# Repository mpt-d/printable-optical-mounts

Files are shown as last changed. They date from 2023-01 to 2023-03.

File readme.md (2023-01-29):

-------------------------------
3D-Printable Optical Components
-------------------------------

## Mission Statement

The objective of this project is to produce a free library of optical components that can be manufactured by users through 3D printing or milling. 

The current scope of the project encompasses a cage system, a post system and various mounts. It does not include hard-to-manufacutre components such as lenses, mirrors and filters

## Disclaimer

This project is not ready for use. Do not attempt to manufacture any of the components.

## Manufacturing Requirements

### Equipment

- FDM or SLA 3D printers
- A hand saw and vice (for cutting cage poles to size)

### Software

- FreeCAD (only if viewing or modifying components)
- A 3D slicer compatible with your 3D printer

### Materials

FDM filament or SLA resin depending on the chosen manufacturing technique.

### Other Parts

- M4 and M6 thread inserts (see BOM)
- M4 thumbscrews 
- M5 grub screws
- M1.6 nylon-tipped grub screws
- Ø6mm aluminium rods (for use in cage system)

## Implemented Modules

### Main Groups:

- 30mm cage system
- Post and pedestal system
- Various compatible optical mounts

### 30mm Cage System

General: 

- [done] Base mat 
- [done] Post holders 
- [done] Posts 
- [done] Pedestals 
- [done] Clamping fork 

Mounts:  

- [done] V-groove lens/laser mount 
- [done] Filter/mirror mount 
- [done] Prism platform 
- [done] Cylindrical object mount 
- [done] XY translation lens holder 
- [done] XY rotation lens holder 
- [done] Iris 

Cage: 

- [part] 90° Junction 
- [done] Side branch mount 
- [part] Mirror clamp 
- [done] Spiral lens holder 
- [done] XY rotation lens holder 
- [done] XY translation lens
- [done] Poles 
- [done] Post mount 
- [done] Structural tie

# Assembly

## Screws

All threads larger than M3 require corresponding thread inserts. These can be pressed to FMD printed components by heating them with a soldering iron. For the M1.6 grub screws used to clamp removable parts in place, threads must be tapped manually. It is recommended to use nylon-tipped set screws to avoid damaging clamped equipment.

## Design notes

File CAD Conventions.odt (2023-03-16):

CAD Conventions

Overview

To maintain homogeneity across all module designs, we should attempt to maintain a common structure across all FreeCAD files. This document hopes to formalise names and hierarchies.

Module Scope

Minimum Viable Module Set | General: - [done] [bom] [drw] Base mat - [done] [bom] [drw] Post holders - [done] [bom] [drw] Posts - [done] [bom] Pedestals - [done] [bom] Clamping fork Mounts: - [done] [bom] [drw] V-groove lens/laser mount - [done] [bom] Filter/mirror mount - [done] [bom] Prism platform Cage: - [done] [bom] Poles - [done] [bom] Post mount - [done] [bom] Structural tie
Preferred Module Set | General: - [done] [bom] [drw] Cylindrical object mount - [done] [bom] XY translation lens holder - [done] [bom] [drw] XY rotation lens holder Cage: - [done] [bom] 90° Junction - [done] [bom] Cross junction - [done] [bom] Side branch mount - [done] [bom] Spiral lens holder - [done] [bom] XY rotation lens holder - [done] [bom] XY translation lens holder - [done] [bom] Pole-to-pole tie
Extended Module Set | General: - Motorised rotating filter mount - [done] [bom] Iris - Optical rail Cage: - Shearing interferometer casing - Adapters for competing cage systems

Document Hierarchy

All geometry (such as Bodies created with Part Design workbench) should be encapsulated within a Part object. Multiple parts can be defined within the same document, but if they are meant to be separate objects, they should be enclosed different Parts.

Parts can be created with a button present in both the Part Design and Part workbenches.

File Naming Conventions

File names should be lower case and must not contain spaces. Descriptors filenames must be separated with dashes.

General format:

<name>_<name>-<descriptor>

Examples:

junction-cross

Junction-corner

post_holder-60mm

post_holder-70mm

Part Naming Conventions

Parts should be given a friendly display name that can contain spaces and capitals.

All geometry within the Part (Bodies, primitives, etc.) should be named in snake_case. The naming of Part Design features and sketches does not matter provided they are descriptive.

Parameter Aliasing

Where possible, dimensions should be referenced from a spreadsheet rather than hard-coded into the sketch or feature. This allows the creation of multiple linked copies of parts whose parameters can be altered independently.

Caution: When creating parametric models, values should be inherited from a single spreadsheet in a central file to avoid dependency loops. For example, if models FILE1 and FILE2 require a common value, they should both inherit it from a spreadsheet in FILE3. FILE1 and FILE2 must not reference each other directly.

Alias Naming Conventions

FreeCAD Parameter aliases start with a sequence that indicates its type followed by its name. All characters should be lower case, and words should be separated by underscores (snake_case).

<parameter key>_<name>

For example, the inner radius of a shaft could be called ri_shaft.

Key | Value
w | Width
h | Height
t | Thickness
wt | Wall Thickness
l | Length
[dr]i | Inner radius/diameter
[dr]o | Outer radius/diameter
[dr]m | Major radius/diameter
[dr]mi | Minor radius/diameter
a | Angle
pt | Pitch
off | Offset
c | Clearance

Configuration Tables

Configuration tables allow parts to be switched between multiple sets of parameters defined in a spreadsheet. This is useful for creating parts which follow the same pattern but have altered dimensions.

Tutorials:

https://www.youtube.com/watch?v=D0f7bkNGAOg&t=346s

https://www.youtube.com/watch?v=nAmwGUuvnjs

## General Design Features

FreeCAD Topological Naming Problem

A major issue in FreeCAD is that the creation of new geometry can cause geometry that depends on it to break. This can result in fillets on the wrong edges, sketches attached to curves and all sorts of weird things.

More information, including how to avoid the issue: https://wiki.freecadweb.org/Topological_naming_problem

Alternatively, the Linkstage3 branch of FreeCAD (maintained by Realthunder) can be used. This includes automatic and backwards-compatible solutions for the topological naming problem that work in most cases:

https://github.com/realthunder/FreeCAD/releases

Fillets

It is recommended to replace sharp edges with fillets to avoid stress concentrations.

For visual consistency across all parts, try to make fillets with lengths of 1mm or 0.5mm.

Design for 3D Printing

To be printed effectively a part must have:

- Good adhesion with the platform.
- No significant overhangs

Parts should have a flat surface that will be in contact with the base during manufacture. Overhangs should be avoided.

Threads

For maximum accessibility, built-in threads below M5 are to be avoided in favour of metal thread inserts. This removes the requirement for a very high-quality 3D printer which some users will have access to. If a built-in thread is required, it can be generated with the Hole feature in the Part Design workbench.

A question about 3D-printing threads:

https://3dprinting.stackexchange.com/questions/3160/printing-screws-is-the-output-usable-m3-or-m4

Drawings

Drawings must be made on the TechDraw workbench. To start a new drawing, click on ‘Insert Page Using Template’ and select ‘A?_Landscape_ISO7200_Pep.svg’. The title block can be filled out by double-clicking on the green highlighted areas. Fields in the title block should be full capitals (I think).

The ‘Insert Projection Group’ button can be used to create first and third angle projections.

The style of dimension arrows can be changed in the ‘Drawing Style’ dropdown in the task dialogue. ISO Referencing may be clearer than the default style.

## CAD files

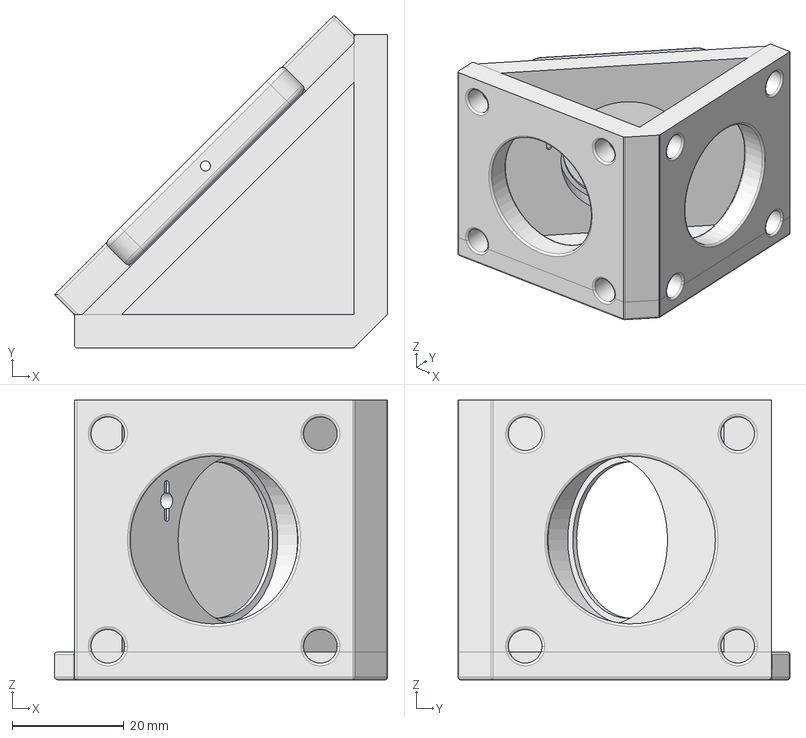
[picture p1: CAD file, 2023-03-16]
cage/30mm/junction-corner.FCStd
59.5 x 59.3 x 50.0 mm
front
junction

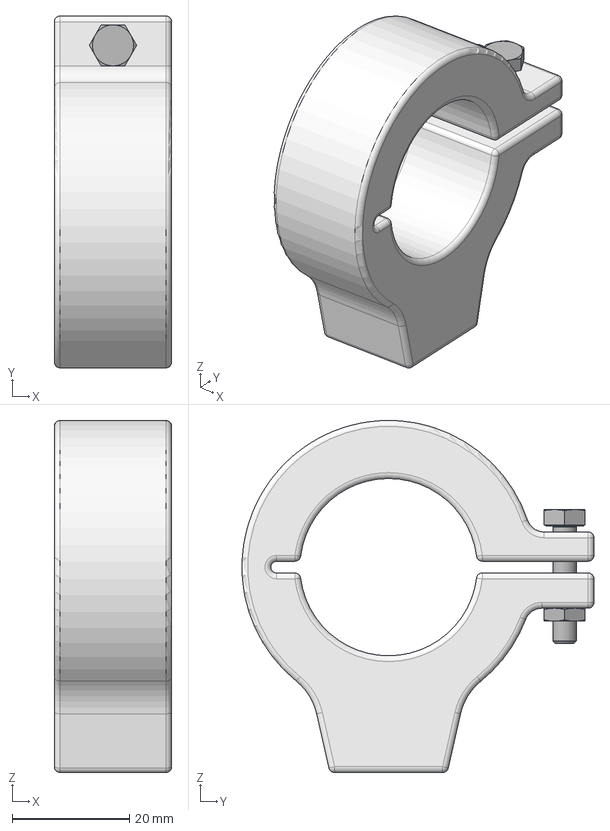
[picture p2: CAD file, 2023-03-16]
mounts/mount-cylinder-30mm.FCStd
20.0 x 60.0 x 60.0 mm
cylindrical_mount
M4x20-Screw
M4-Nut

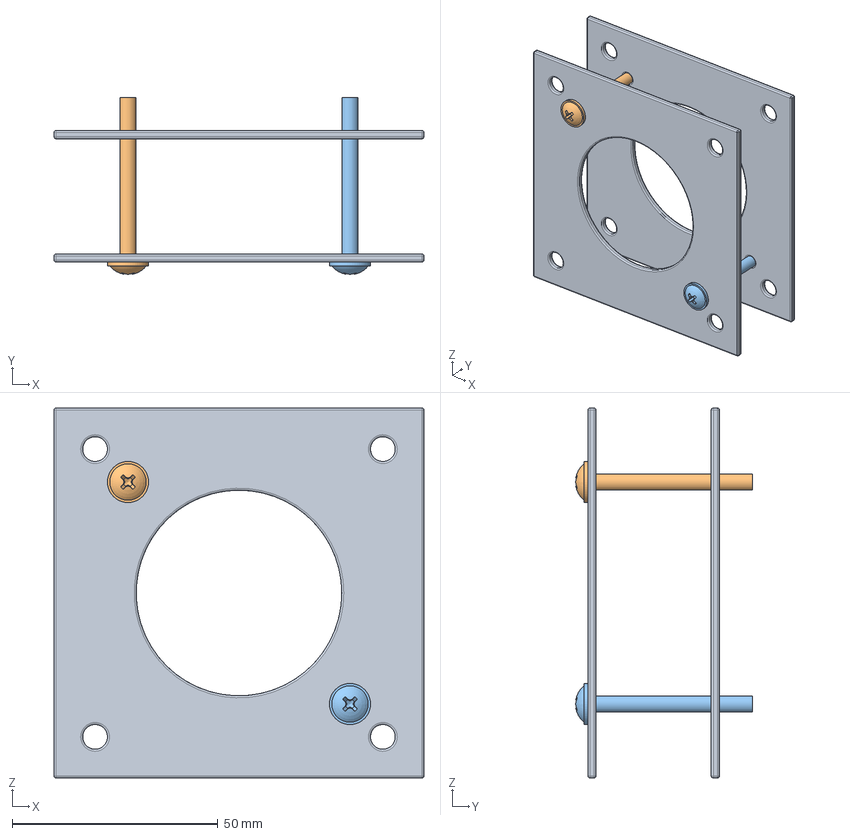
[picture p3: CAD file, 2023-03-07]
mounts/optical holder mount/optical holder mount.FCStd
90.0 x 43.0 x 90.0 mm
M4x40-Screw001
M4x40-Screw

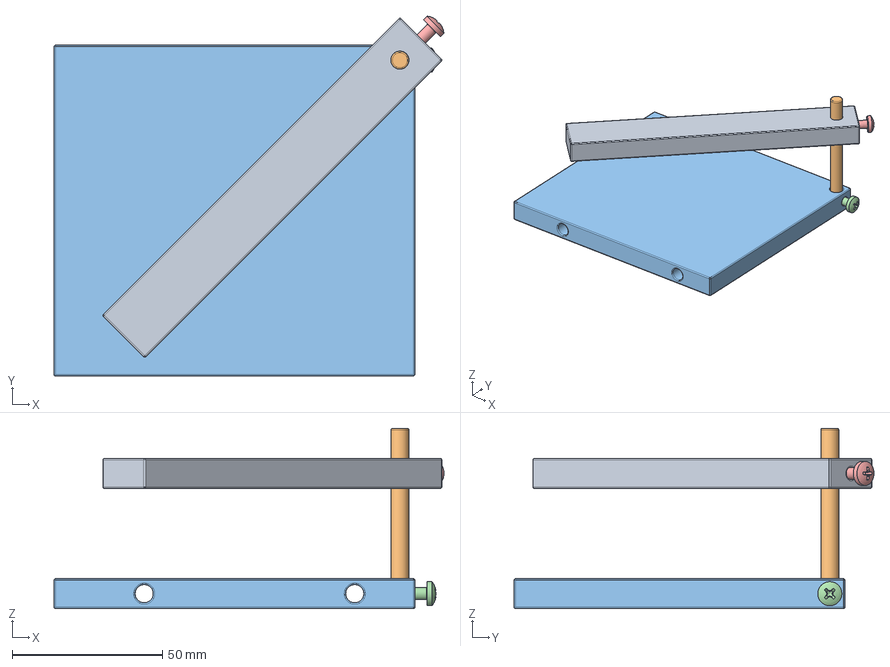
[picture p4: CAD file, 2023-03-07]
mounts/platform mount/platform holder.FCStd
129.7 x 119.7 x 60.0 mm
M4x5-Screw
M4x10-Screw

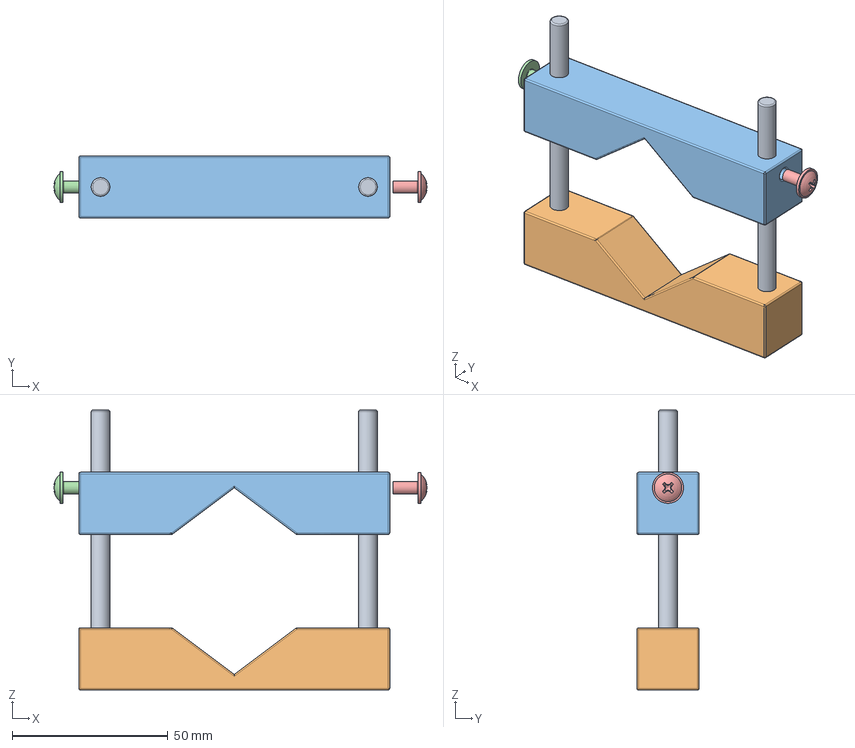
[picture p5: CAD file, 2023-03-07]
mounts/v-groove mount/v groove mount.FCStd
119.9 x 20.0 x 90.0 mm
pole x 2
bottom
top
M4x8-Screw
M4x8-Screw001

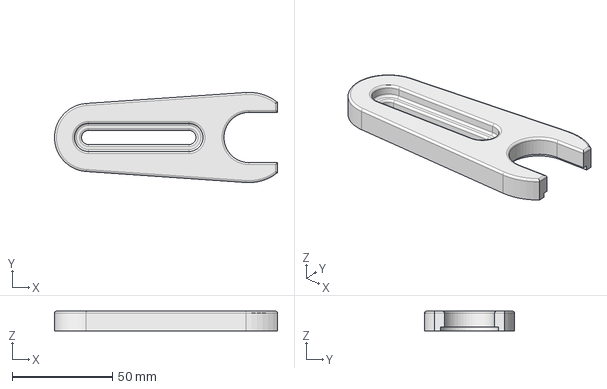
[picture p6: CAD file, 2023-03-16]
posts/clamping_fork.FCStd
111.1 x 44.9 x 9.80 mm

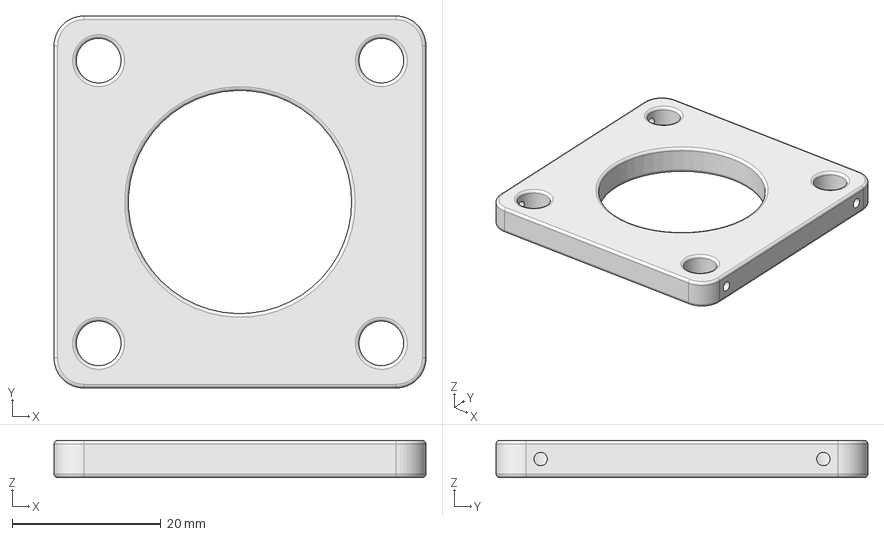
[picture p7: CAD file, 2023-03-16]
cage/30mm/tie.FCStd
50.0 x 50.0 x 5.00 mm

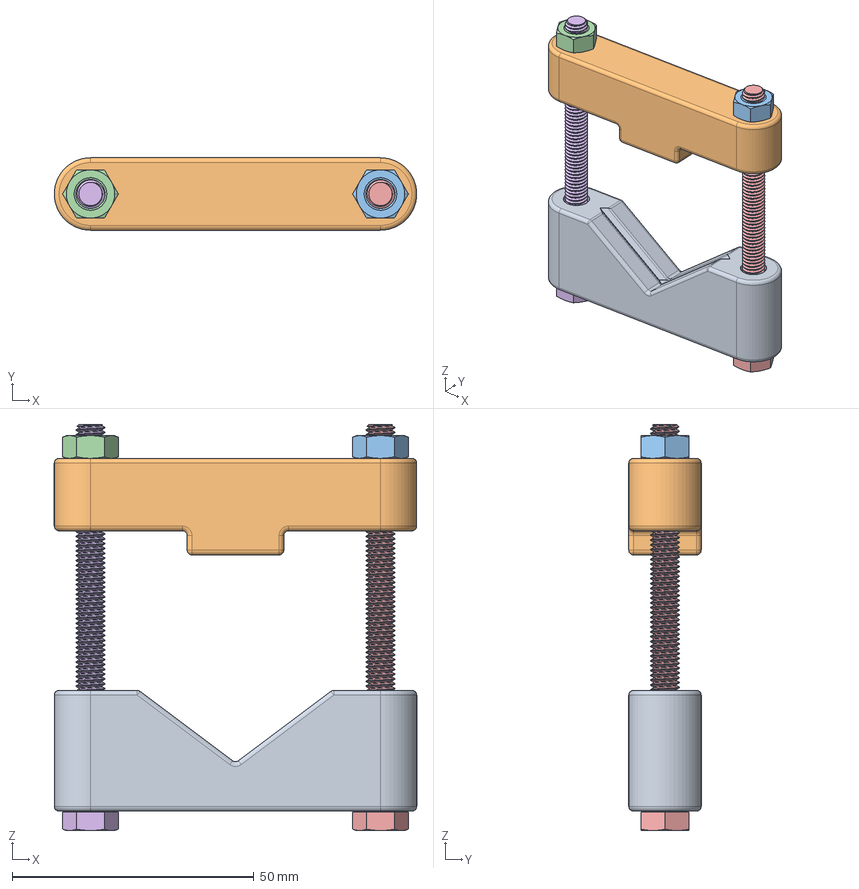
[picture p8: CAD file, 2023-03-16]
mounts/mount-v_groove.FCStd
75.0 x 15.0 x 84.0 mm
bottom
top
M6-Nut
M6-Nut001
M6x80-Screw
M6x80-Screw001

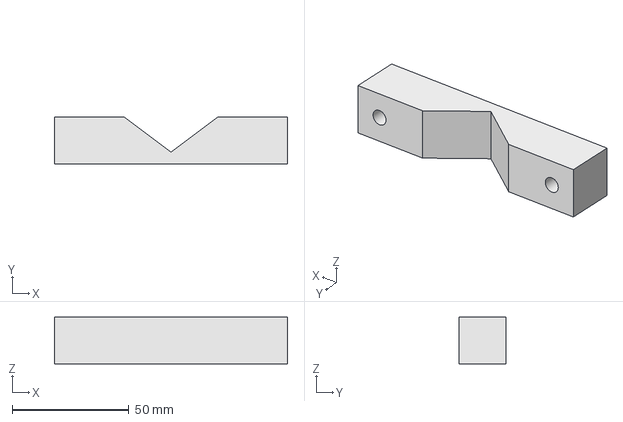
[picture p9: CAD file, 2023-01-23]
mounts/v-groove mount/bottom v groove.FCStd
100.0 x 20.0 x 20.0 mm

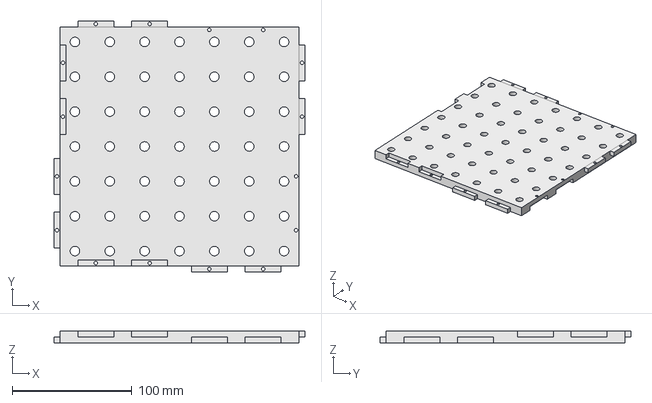
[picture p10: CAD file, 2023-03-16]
posts/base_mat.FCStd
210.0 x 210.0 x 10.0 mm

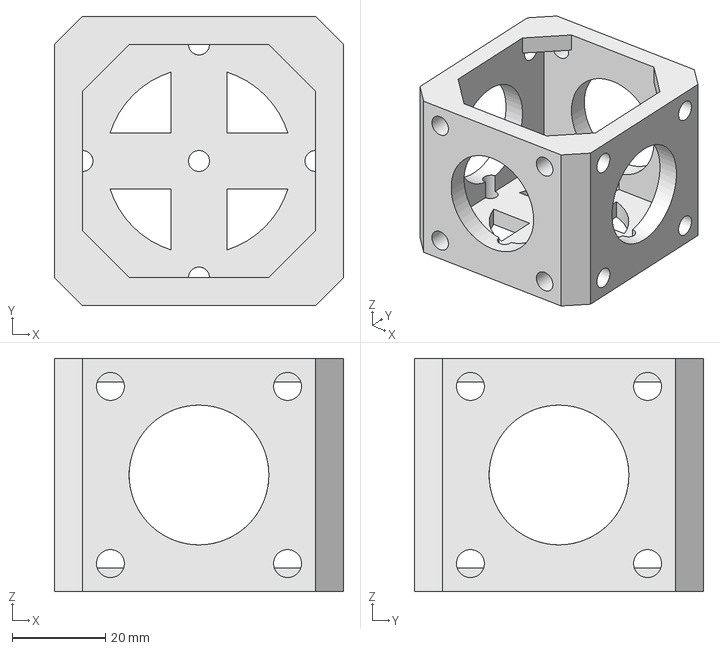
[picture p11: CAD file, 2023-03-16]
cage/30mm/junction-cross.FCStd
62.0 x 62.0 x 50.0 mm

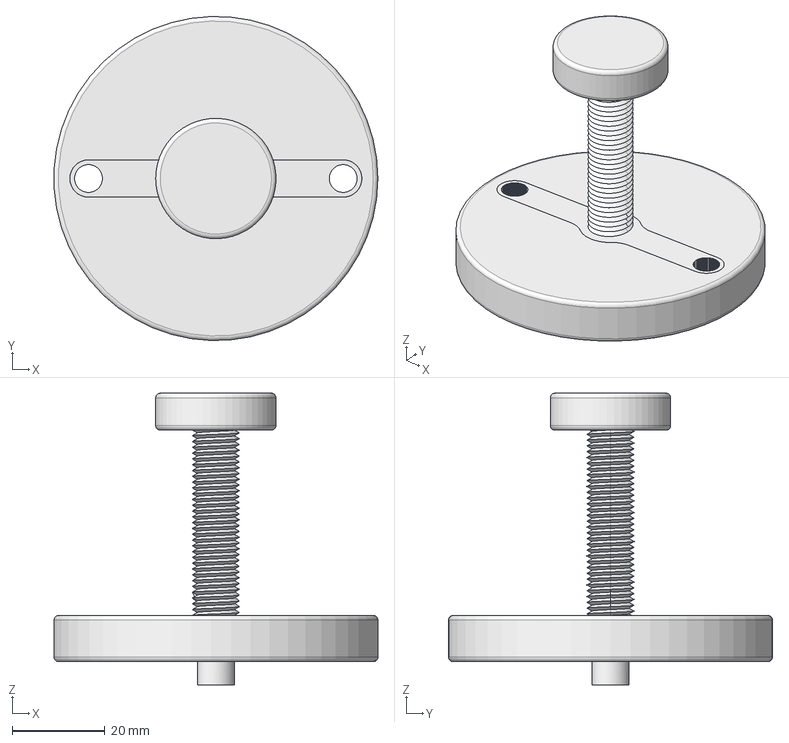
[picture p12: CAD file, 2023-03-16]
mounts/mount-prism_platform.FCStd
69.9 x 70.0 x 63.0 mm
base
top
thumbscrew
_Element

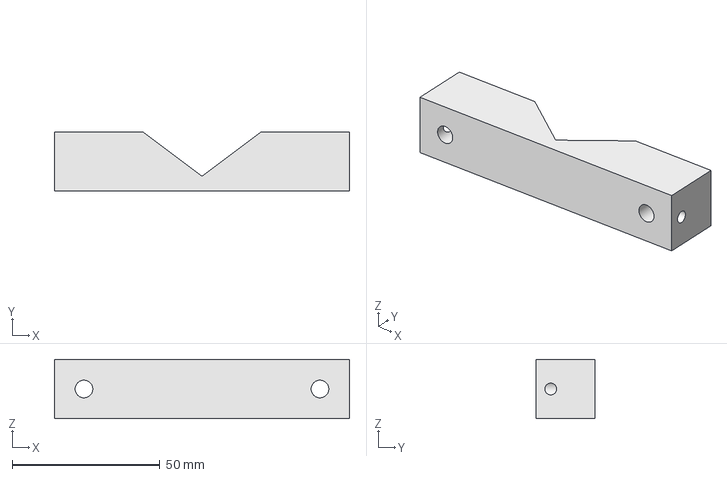
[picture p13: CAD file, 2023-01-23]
mounts/v-groove mount/top v groove.FCStd
100.0 x 20.0 x 20.0 mm

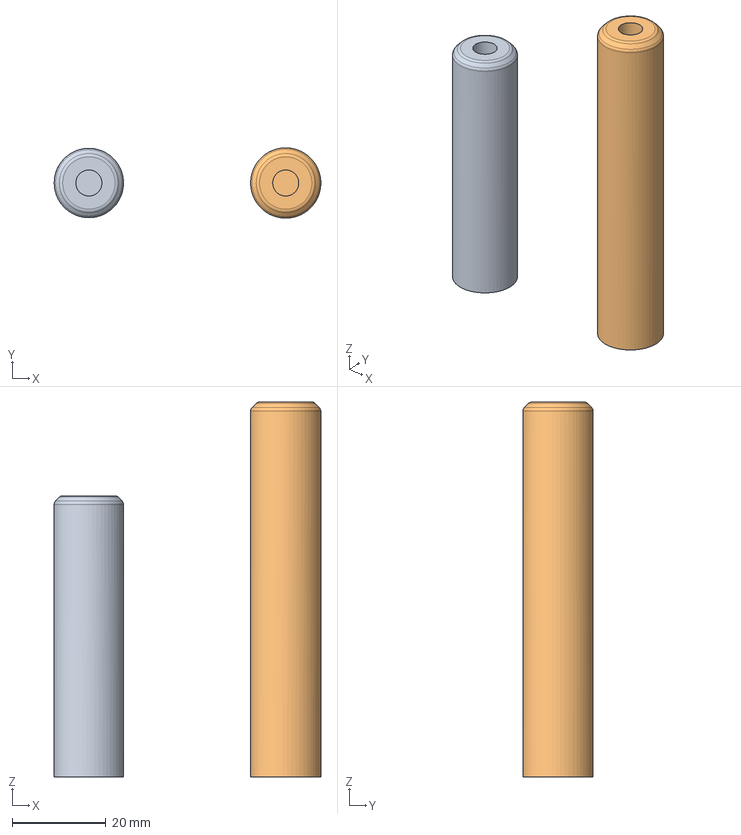
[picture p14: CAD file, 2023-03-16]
posts/posts.FCStd
56.9 x 15.0 x 80.0 mm
post
post001

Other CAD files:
cage/30mm/cage_mount-spiral.FCStd
mounts/mount-tran_xy.FCStd
posts/pedestals.FCStd
cage/30mm/cage_mount-tran_xy.FCStd
cage/30mm/cage-30mm-params.FCStd
cage/30mm/cage_mount-filter_mirror.FCStd
cage/30mm/cage_mount-rot_xy.FCStd
cage/30mm/junction-side.FCStd
cage/30mm/pole.FCStd
cage/30mm/pole_to_pole_tie.FCStd
cage/30mm/post_mount.FCStd
mounts-old/XY screw lens holder.FCStd
mounts-old/XY translation mount/XY screw lens holder.FCStd
mounts-old/holder-v_groove.FCStd
mounts-old/iris.FCStd
mounts-old/lens_holder-rot_xy.FCStd
mounts-old/mount-cylinder-30mm.FCStd
mounts-old/mount-prism_platform.FCStd
mounts/XY screw lens holder.FCStd
mounts/XY translation mount/XY screw lens holder.FCStd
mounts/iris.FCStd
mounts/mount-rot_xy.FCStd
posts/post-params.FCStd
posts/post_holder.FCStd

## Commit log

2023-01-13 Add poles and ties with a global spreadsheet for parameters.
    [cage-30mm-params.FCStd, pole-100mm.FCStd, pole-200mm.FCStd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]
2023-01-15 Add 30mm Side Mount
    [cage-30mm-params.FCStd, side_mount.FCStd]
2023-01-15 Add pole-to-pole tie
    [pole_to_pole_tie.FCStd, side_mount.FCStd, tie.FCStd]
2023-01-16 Add Mirror Holder and 90° Connector
    [cage-30mm-params.FCStd, connector-right_angle.FCStd, mirror_holder.FCStd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]
2023-01-21 Add cross junction
    [junction-cross.FCStd]
2023-01-21 Add 30mm cage post mount
    [junction-cross.FCStd, post_mount.FCStd, tie.FCStd]
2023-01-21 Fix Side Mount
    [cage-30mm-params.FCStd, side_mount.FCStd, tie.FCStd]
2023-01-22 Remove overhang in junction-cross
    [cage-30mm-params.FCStd, junction-cross.FCStd, post_mount.FCStd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]
2023-01-22 Rename junction-corner
    [connector-right_angle.FCStd, junction-corner.FCStd, junction-cross.FCStd]
2023-01-22 Edit readme
    [junction-cross.FCStd, post_mount.FCStd]
2023-01-22 Add lens_holder-screw
    [cage-30mm-params.FCStd, lens_holder-screw.FCStd, mirror_holder.FCStd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]
2023-01-22 Add lens_holder-spiral
    [lens_holder-screw.FCStd, lens_holder-spiral.FCStd]
2023-01-23 Add mounts
    [100mm Pole.FCStd, 60mm pole.FCStd, XY screw lens holder.FCStd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]
2023-01-24 add folder
    [Clamping_Fork[598].FCStd]
2023-01-24 Misc changes
    [junction-cross.FCStd, lens_holder-spiral.FCStd]
2023-01-24 Add post holder
    [post-params.FCStd, post_holder-60mm.FCStd]
2023-01-24 Rename post holder, add posts.
    [post-params.FCStd, post_holder-60mm.FCStd, post_holder.FCStd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]
2023-01-24 Add pedestals
    [pedestals.FCStd, post-params.FCStd, post_holder.FCStd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]
2023-01-24 Add Clamping Fork
    [clamping_fork.FCStd]
2023-01-24 Update post parameters
    [clamping_fork.FCStd, pedestals.FCStd, post-params.FCStd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]
2023-01-24 Fix coincident constraints
    [pole_to_pole_tie.FCStd]
2023-01-25 Add iris
    [iris.FCStd]
2023-01-25 Mostly complete iris
    [cage-30mm-params.FCStd, iris.FCStd]
2023-01-25 Replace chamfer with fillet
    [clamping_fork.FCStd]
2023-01-26 Add fillets to sharp edges on cage components.
    [clamping_fork.FCStd, junction-corner.FCStd, junction-cross.FCStd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]
2023-01-26 Add fillets to posts
    [clamping_fork.FCStd, pedestals.FCStd, post_holder.FCStd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]
2023-01-26 Add adjustable XY rotation holder
    [lens_holder-k_xy.FCStd]
2023-01-26 pedetal and post holder upload
    [Clamping_Fork[598].FCStd, Pedestal.FCStd, Post_Holder.FCStd]
2023-01-26 Create prism holder 15mm.FCStd
    [prism holder 15mm.FCStd]
2023-01-26 Add post-mounted XY rotation lens holder
    [lens_holder-rot_xy.FCStd]
2023-01-28 Add base Base Mat
    [base_mat.FCStd]
2023-01-28 Tweak post parameters
    [post-params.FCStd, post_holder.FCStd]
2023-01-28 Adjust threads to accommodate inserts
    [base_mat.FCStd, clamping_fork.FCStd, pedestals.FCStd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]
2023-01-28 Remove broken assemblies
    [XY screw lens holder.FCStd, iris.FCStd, lens_holder-spiral.FCStd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]
2023-01-30 Fix corner junction
    [junction-corner.FCStd]
2023-01-30 Slight changes
    [posts.FCStd, tie.FCStd]
2023-02-12 Add cylinder mount
    [cylinder_mount-30mm.FCStd, iris.FCStd]
2023-02-12 Add modified V-groove holder
    [holder-v_groove.FCStd]
2023-02-13 Add alternative prism platform
    [holder-v_groove.FCStd, mount-prism_platform.FCStd]
2023-02-24 Many changes
    [XY screw lens holder.FCStd, base_mat.FCStd, cage-30mm-params.FCStd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]
2023-03-07 Completed mounts
    [100mm Pole.FCStd, 60mm pole.FCStd, XY screw lens holder.FCStd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]
2023-03-07 Some changes
    [iris.FCStd, lens_holder-rot_xy.FCStd, mount-cylinder-30mm.FCStd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]
2023-03-16 Rename mounts dir
    [XY screw lens holder.FCStd, base_mat.FCStd, bottom v groove.FCStd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]
2023-03-16 Sanitise mounts directory
    [iris.FCStd, lens_holder-screw.FCStd, mount-cylinder-30mm.FCStd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]
2023-03-16 Rename side junction
    [junction-side.FCStd, mount-cylinder-30mm.FCStd, side_mount.FCStd]
2023-03-16 Rename cage_moint-rot_xy
    [cage_mount-rot_xy.FCStd, lens_holder-rot_xy.FCStd]
2023-03-16 Rename mount-tran_xy
    [lens_holder-screw.FCStd, mount-tran_xy.FCStd]
2023-03-16 Rename more things
    [cage_mount-spiral.FCStd, cage_mount-tran_xy.FCStd, lens_holder-spiral.FCStd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]
2023-03-16 Fix invalid file linke due to rename
    [junction-corner.FCStd, junction-cross.FCStd, tie.FCStd]
